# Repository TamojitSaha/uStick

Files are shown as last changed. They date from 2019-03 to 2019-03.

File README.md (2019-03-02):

# uStick
μStick (pronounced as "mu stick")or uStick is a 32bit Arm Cortex M0+ based Arduino Compatible micro development board specially designed for battery driven projects/products.
The project is available to order from [OSH Park](https://oshpark.com/projects/SfXMe0NL).

## Features:
- Micro Dev Board (39mm x 15mm)
- ATSAMD11C14 -- 32bit Arm Cortex M0+ 
- 16kb flash, 4kb SRAM
- Battery charging modes(user configurable): 
	- 1. USB 100mA
	- 2. USB 500mA
	- 3. Resistor settable charging current upto 1.6A
- Low noise LDO
  - low Output-VoltageNoise:12 μVRMSTypical
  - PSRRat 1 kHz:75 dB Typical
  - OutputVoltageTolerance(VOUT≥3.3 V): ±2%
  - Low IQ(Enabled,No Load):30 μA Typical
  - Low Dropout(VOUT≥3.3 V): 95 mV Typical at 500 mA Load
- Choosable EEPROM(16-512 MegaBit, refer to [this](https://github.com/Marzogh/SPIMemory) library)
- Auto charging and system power management
- Charging status and power good indicator
- Button configurable for reset or general use (pin D15) with debouncing.
  -  Use as reset (default), with bootloader entry via reset double-tap
  - Use as a general purpose button, with bootloader entry by holding during powerup.
- ESD protection on USB D+ and D- lines
- 9 solder jumpers on PCB bottom for configuration flexibility
- Arduino compatible (use the Arduino IDE to upload)

## Design Layout

&nbsp;&nbsp;

## License
The source files are released under [CC-BY-SA 4.0](https://creativecommons.org/licenses/by-sa/4.0/).



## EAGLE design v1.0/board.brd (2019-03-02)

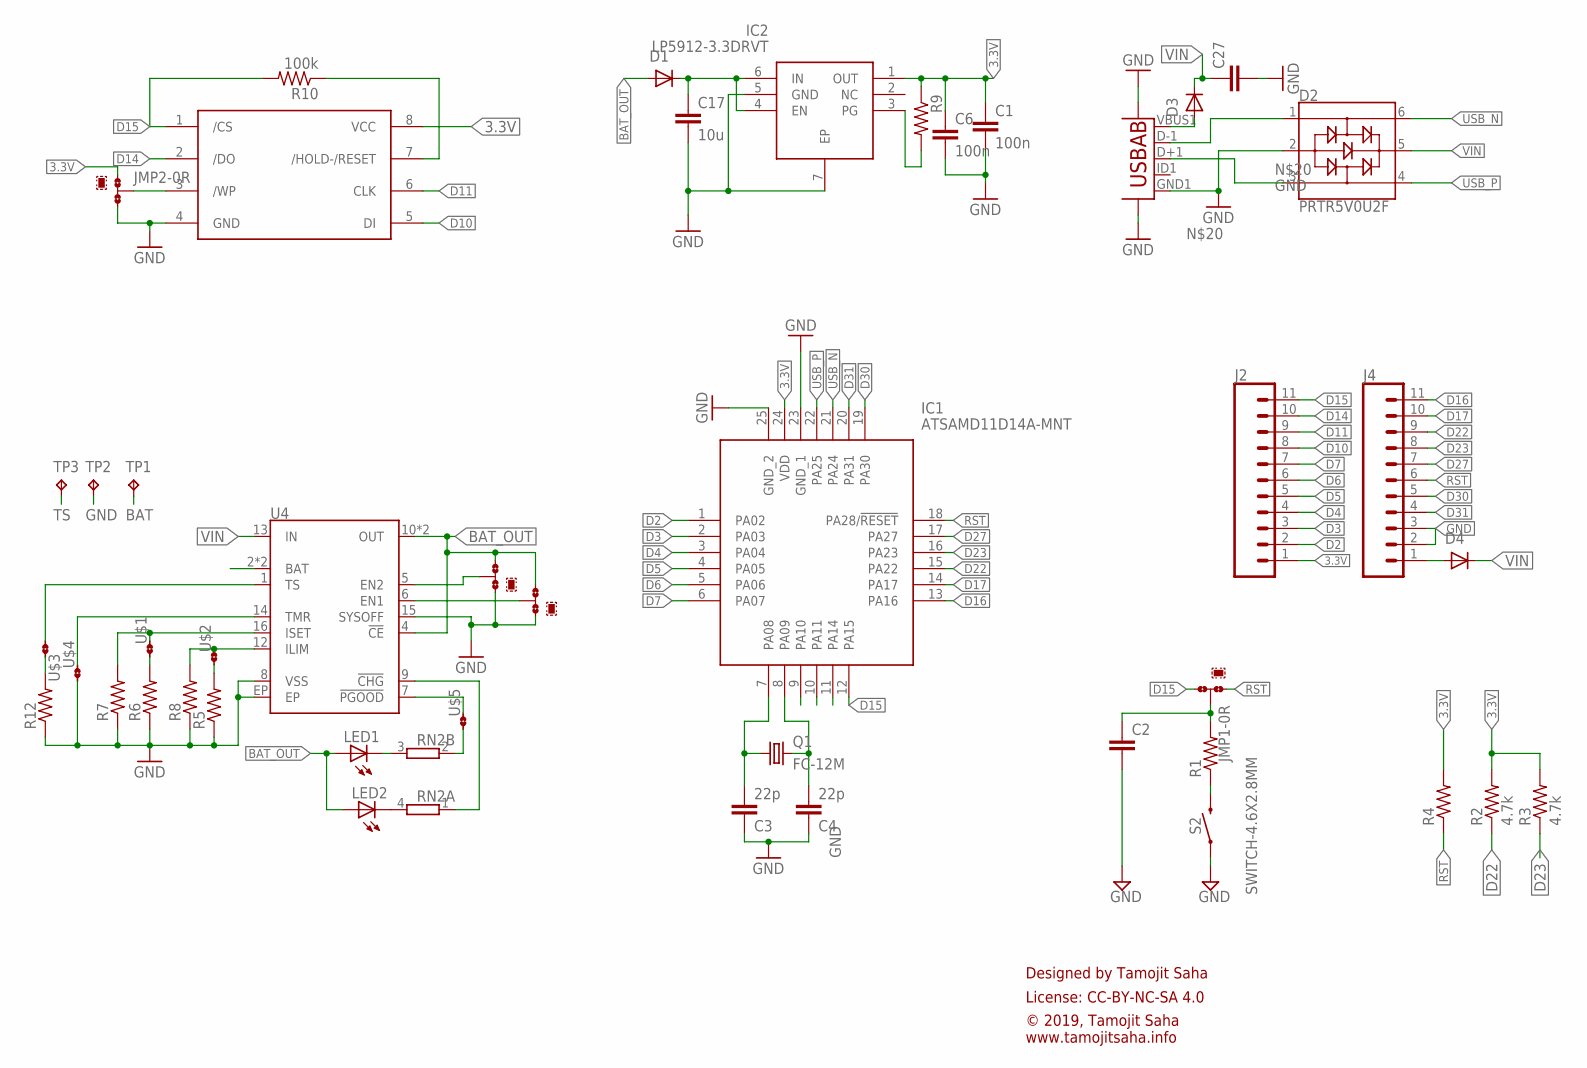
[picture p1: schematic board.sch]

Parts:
C1, C6: 100n; C0402
C2: C-EUC0402; C0402
C3, C4: 22p; C0402
C17: 10u; C0603
C27: C-EUC0603; C0603
D1, D3, D4: PMEG1030; SOD323(F)
D2: PRTR5V0U2F; SOT886
EEPROM1: W25Q128JVPIQ; SON127P600X500X80-9N
IC1: ATSAMD11D14A-MNT; QFN50P400X400X90-25N
IC2: LP5912-3.3DRVT; WSON-6
J2, J4: CONN_111X11_NO_SILK; 1X11_NO_SILK
JMP1, JMP2, JMP3, JMP4: 0R-JUMPA; A0R-JMP
LED1, LED2: LED_ESML0603; LED_SML0603
Q1: FC-12M
R1, R4, R5, R6, R7, R8, R9, R12: R-US_R0402; R0402
R2, R3: 4.7k; R0402
R10: 100k; R0402
RN2: 2R-NEXB24V; EXB24V
S2: SWITCH-4.6X2.8MM; TACTILE_SWITCH_SMD_4.6X2.8MM
TP1, TP2, TP3: TPB1,27; B1,27
U3: USB""; USB-MICRO-SMD
U4: BQ24075; PVQFN-N16
U$1, U$2, U$3, U$4, U$5: JMP-2-NO-0402

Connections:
3.3V: C1.1, C6.1, EEPROM1.8 (VCC), IC1.24 (VDD), IC2.1 (OUT), J2.1, JMP2.1, R2.2, R3.2, R4.2, R9.1
BAT: TP1.TP, U4.2 (BAT), U4.3 (BAT)
BAT_OUT: D1.2 (A), JMP3.3, JMP4.3, LED1.A, LED2.A, U4.4 (!CE!), U4.10 (OUT), U4.11 (OUT)
D2: IC1.1 (PA02), J2.2
D3: IC1.2 (PA03), J2.3
D4: IC1.3 (PA04), J2.4
D5: IC1.4 (PA05), J2.5
D6: IC1.5 (PA06), J2.6
D7: IC1.6 (PA07), J2.7
D10: EEPROM1.5 (DI), IC1.9 (PA10), J2.8
D11: EEPROM1.6 (CLK), IC1.10 (PA11), J2.9
D14: EEPROM1.2 (/DO), IC1.11 (PA14), J2.10
D15: EEPROM1.1 (/CS), IC1.12 (PA15), J2.11, JMP1.3, R10.2
D16: IC1.13 (PA16), J4.11
D17: IC1.14 (PA17), J4.10
D22: IC1.15 (PA22), J4.9, R2.1
D23: IC1.16 (PA23), J4.8, R3.1
D27: IC1.17 (PA27), J4.7
D30: IC1.19 (PA30), J4.5
D31: IC1.20 (PA31), J4.4
GND: C1.2, C2.2, C3.1, C4.1, C6.2, C17.2, C27.2, D2.2, EEPROM1.4 (GND), IC1.23 (GND_1), IC1.25 (GND_2), IC2.5 (GND), IC2.7 (EP), J4.2, J4.3, JMP2.3, JMP3.1, JMP4.1, R5.1, R6.1, R7.1, R8.1, R12.1, S2.1, S2.2 (1), TP2.TP, U3.GND1 (GND), U3.SH1, U3.SH2, U4.8 (VSS), U4.15 (SYSOFF), U4.EP, U$4.1
unnamed: LED1.C, RN2.3 (2)
unnamed: C3.2, IC1.7 (PA08), Q1.1
unnamed: D2.1, U3.D-1 (D-)
unnamed: D2.3, U3.D+1 (D+)
unnamed: R6.2, U$1.1
unnamed: R7.2, U4.16 (ISET), U$1.2
unnamed: C4.2, IC1.8 (PA09), Q1.2
unnamed: C2.1, JMP1.2, R1.2
unnamed: R12.2, U$3.2
unnamed: R5.2, U$2.1
unnamed: R8.2, U4.12 (ILIM), U$2.2
unnamed: U4.14 (TMR), U$4.2
unnamed: C17.1, D1.1 (K), IC2.4 (EN), IC2.6 (IN)
unnamed: JMP4.2, U4.5 (EN2)
unnamed: RN2.2 (1), U$5.1
unnamed: LED2.C, RN2.4 (2)
unnamed: JMP3.2, U4.6 (EN1)
unnamed: RN2.1, U4.9 (!CHG!)
unnamed: U4.7 (!PGOOD!), U$5.2
unnamed: D3.2 (A), U3.VBUS1 (VBUS)
unnamed: D4.2 (A), J4.1
unnamed: IC2.3 (PG), R9.2
unnamed: EEPROM1.3 (/WP), JMP2.2
unnamed: EEPROM1.7 (/HOLD-/RESET), R10.1
unnamed: R1.1, S2.3 (2), S2.4 (2)
RST: IC1.18 (PA28/!RESET), J4.6, JMP1.1, R4.1
TS: TP3.TP, U4.1 (TS), U$3.1
USB_N: D2.6, IC1.21 (PA24)
USB_P: D2.4, IC1.22 (PA25)
VIN: C27.1, D2.5, D3.1 (K), D4.1 (K), U4.13 (IN)

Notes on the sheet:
Designed by Tamojit Saha
License: CC-BY-NC-SA 4.0
© 2019, Tamojit Saha www.tamojitsaha.info

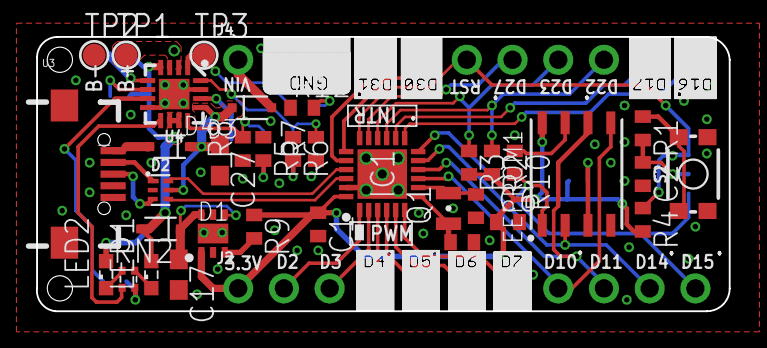
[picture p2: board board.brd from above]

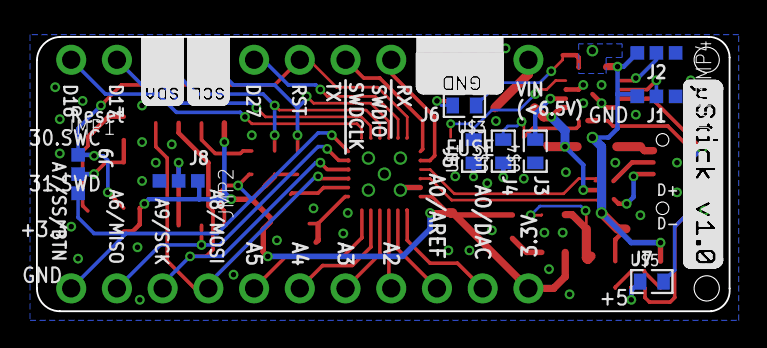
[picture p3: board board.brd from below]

Board: 2 copper layers, 38.5 x 15.2 mm, 46 parts (9 on the bottom side), 51 nets.

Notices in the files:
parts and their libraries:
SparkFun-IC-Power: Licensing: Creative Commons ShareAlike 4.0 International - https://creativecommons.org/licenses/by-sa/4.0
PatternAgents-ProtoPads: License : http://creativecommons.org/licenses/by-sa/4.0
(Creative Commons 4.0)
